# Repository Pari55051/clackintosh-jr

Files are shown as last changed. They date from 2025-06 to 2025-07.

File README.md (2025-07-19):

# Clackintosh Jr.
A macropad to accompany my mac and my keyboard 'Clackintosh'

## Features
- 8 mechanical keys
- Rotary encoder for volume up/down _ its switch as mute button
- 0.91" SSD1306 OLED display
- per-key RGB light
- Xiao RP2040 and KMK firmware

Each key launches a different app on macOS, the rotary encoder controls volume, and the OLED provides live feedback.

## Screenshots
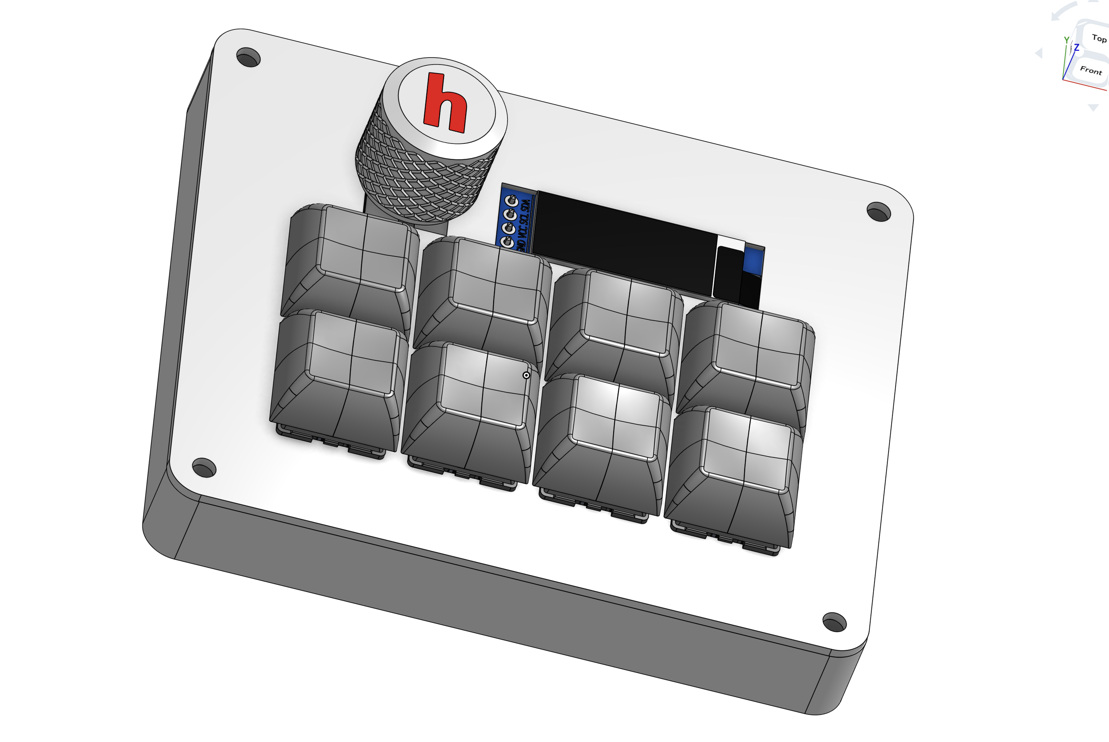
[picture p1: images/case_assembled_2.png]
case_assembled_2

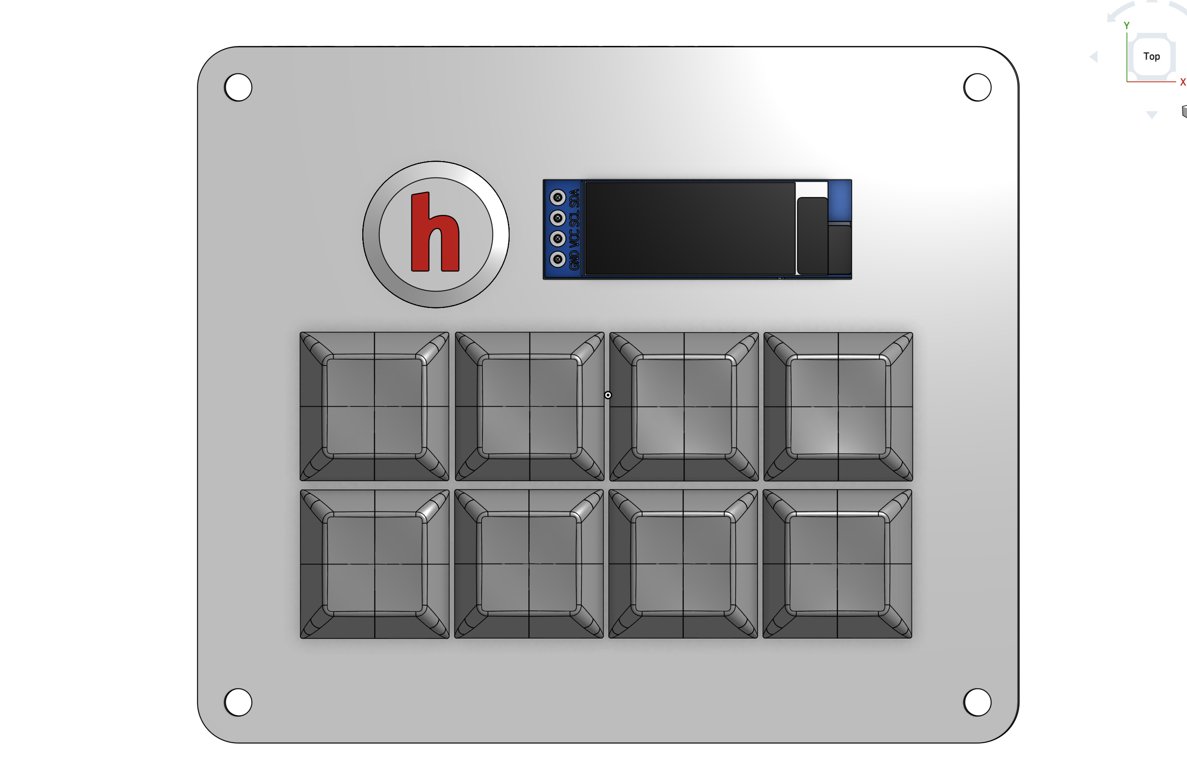
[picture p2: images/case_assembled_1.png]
case_assembled_1

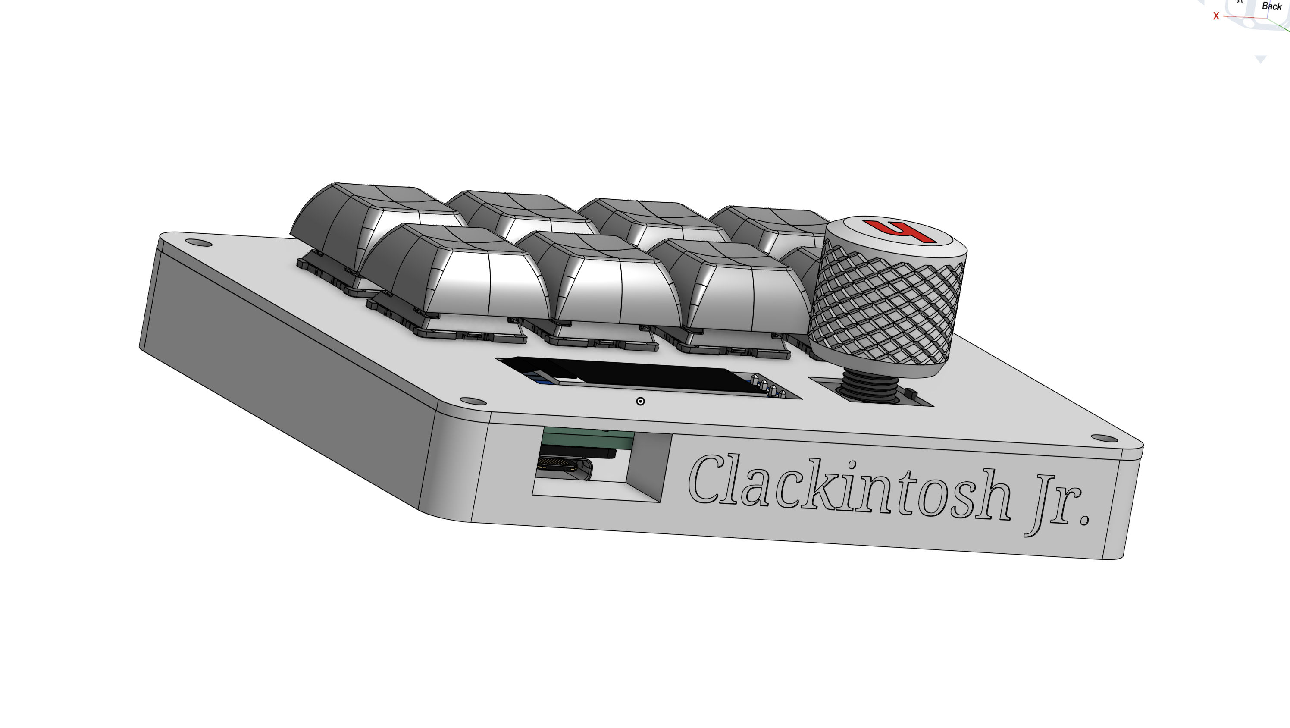
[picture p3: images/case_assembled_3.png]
case_assembled_3


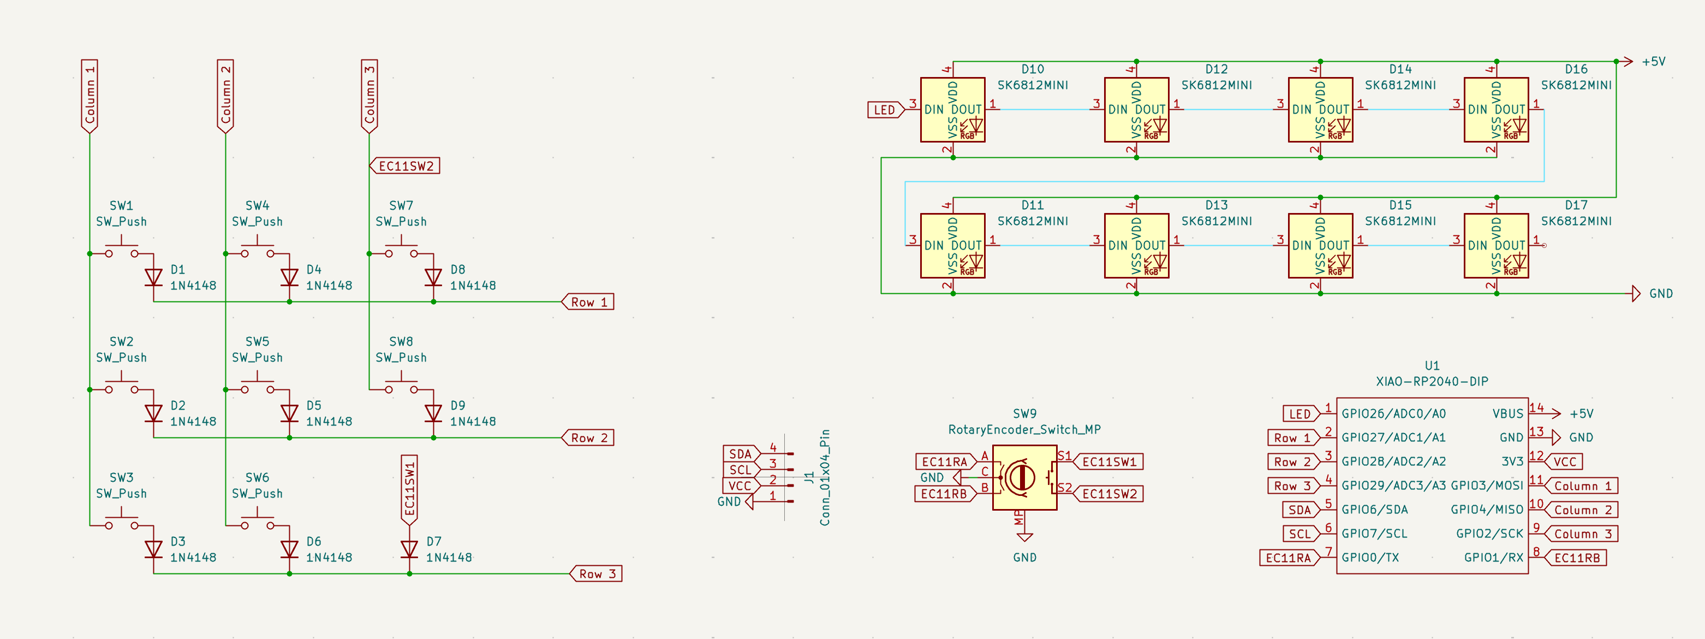
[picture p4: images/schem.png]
pcb_schematics

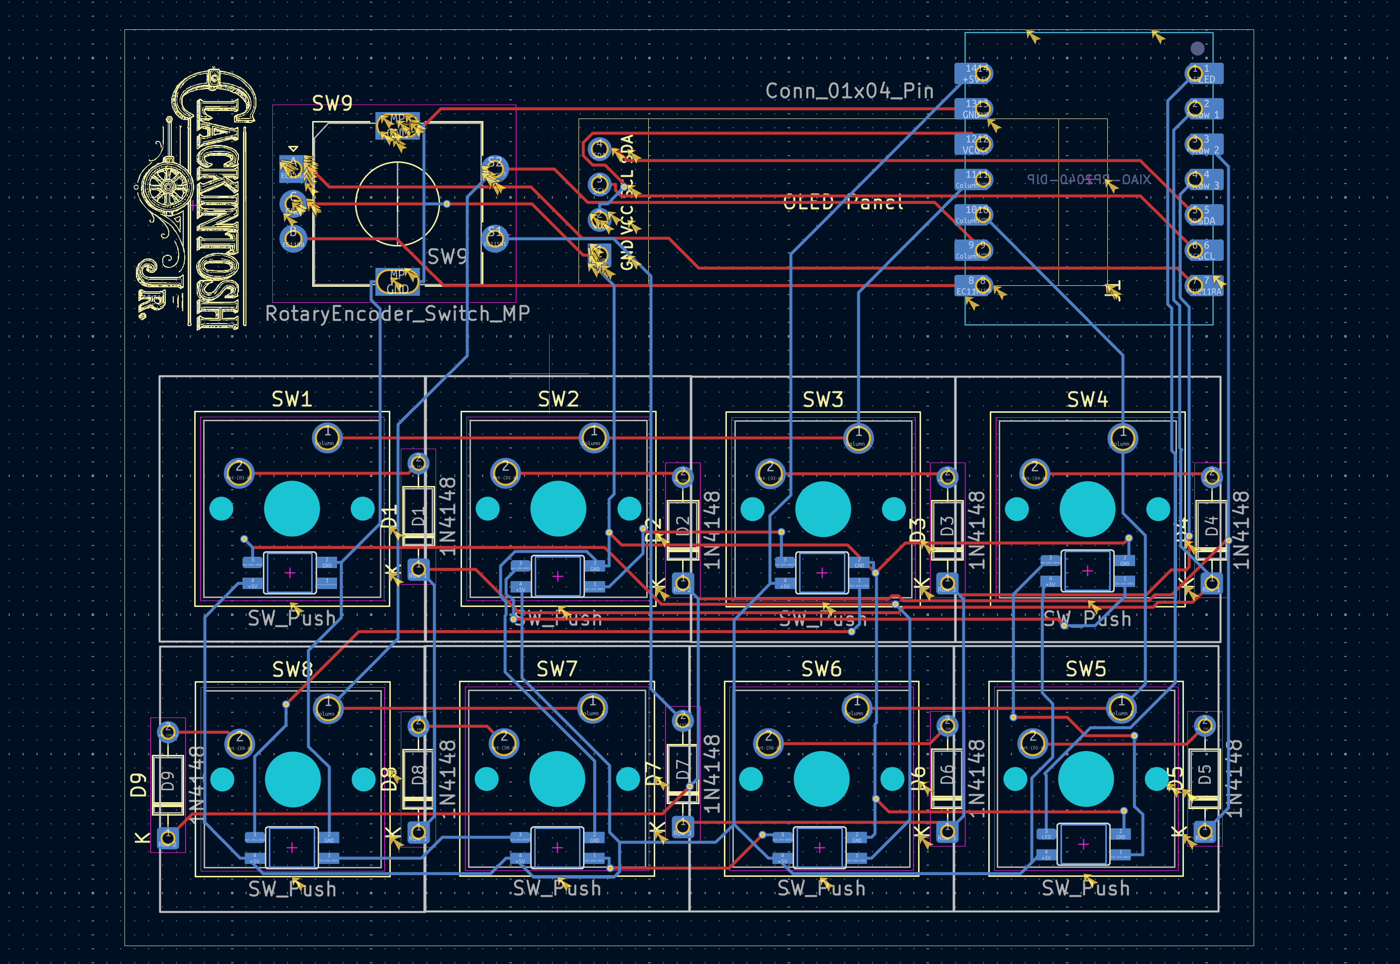
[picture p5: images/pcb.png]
pcb

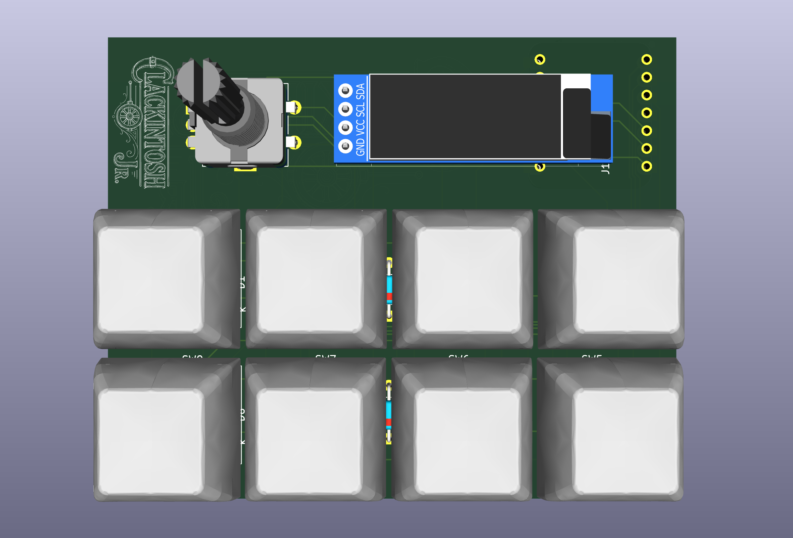
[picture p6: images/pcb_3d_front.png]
pcb_3d_front

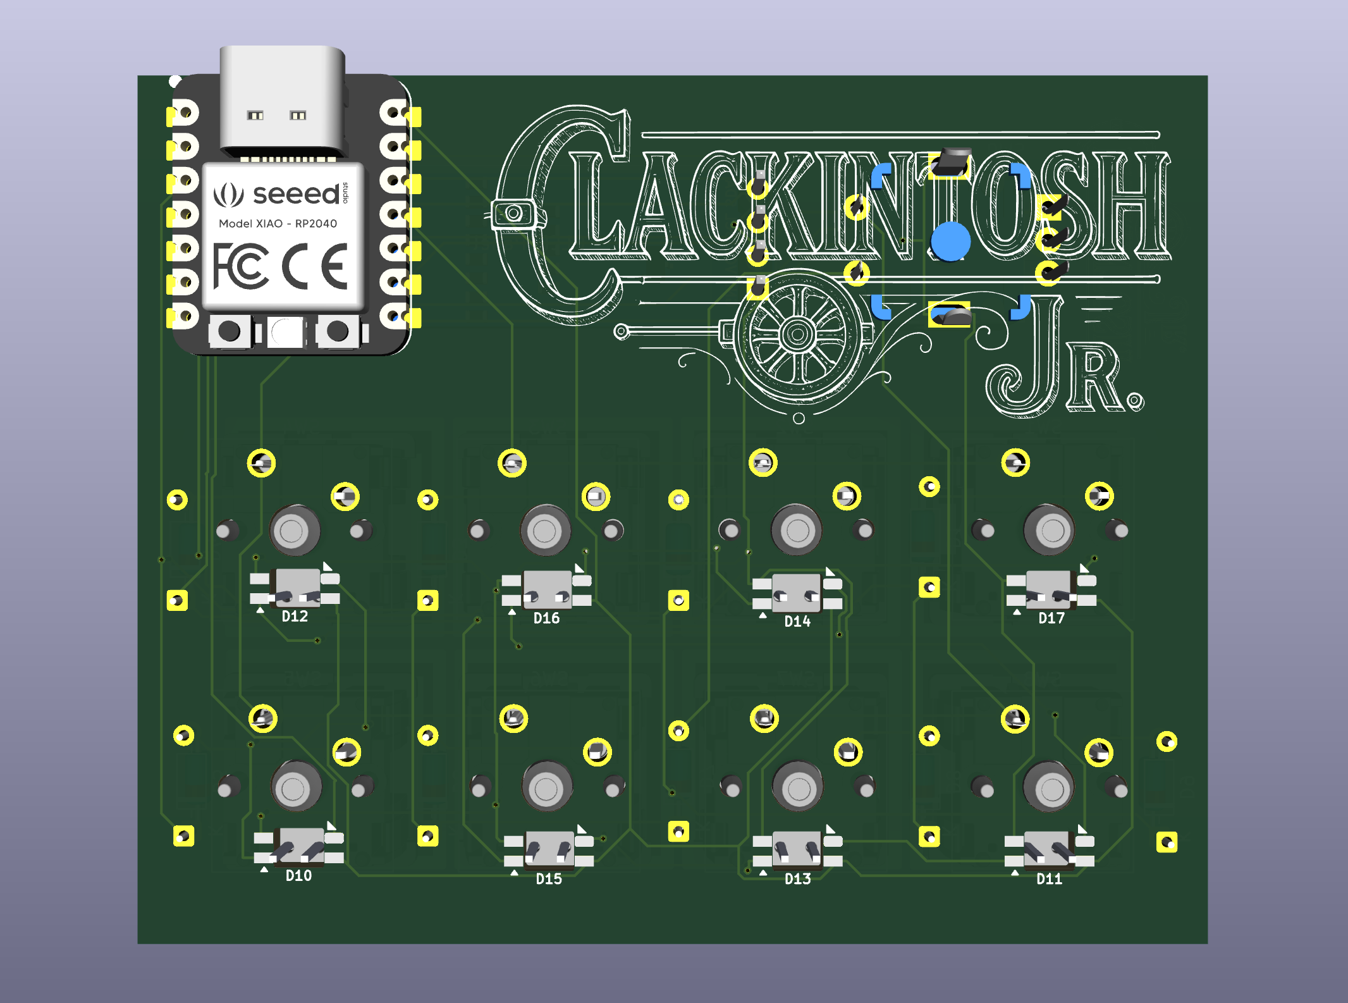
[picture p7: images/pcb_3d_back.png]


## BOM

| Item | Qty |
|---|-----|
| Seeed Xiao RP2040 | 1 |
| Mechanical switches | 8 |
| Keycaps | 8 |
| EC11Rotary Encoder | 1 |
| 0.91" OLED display | 1 |
| Diodes (for matrix) | 9 |
| PCB | 1 |
| 3D printed case (top + bottom) | 1 |
| Screws (case) | 4 |

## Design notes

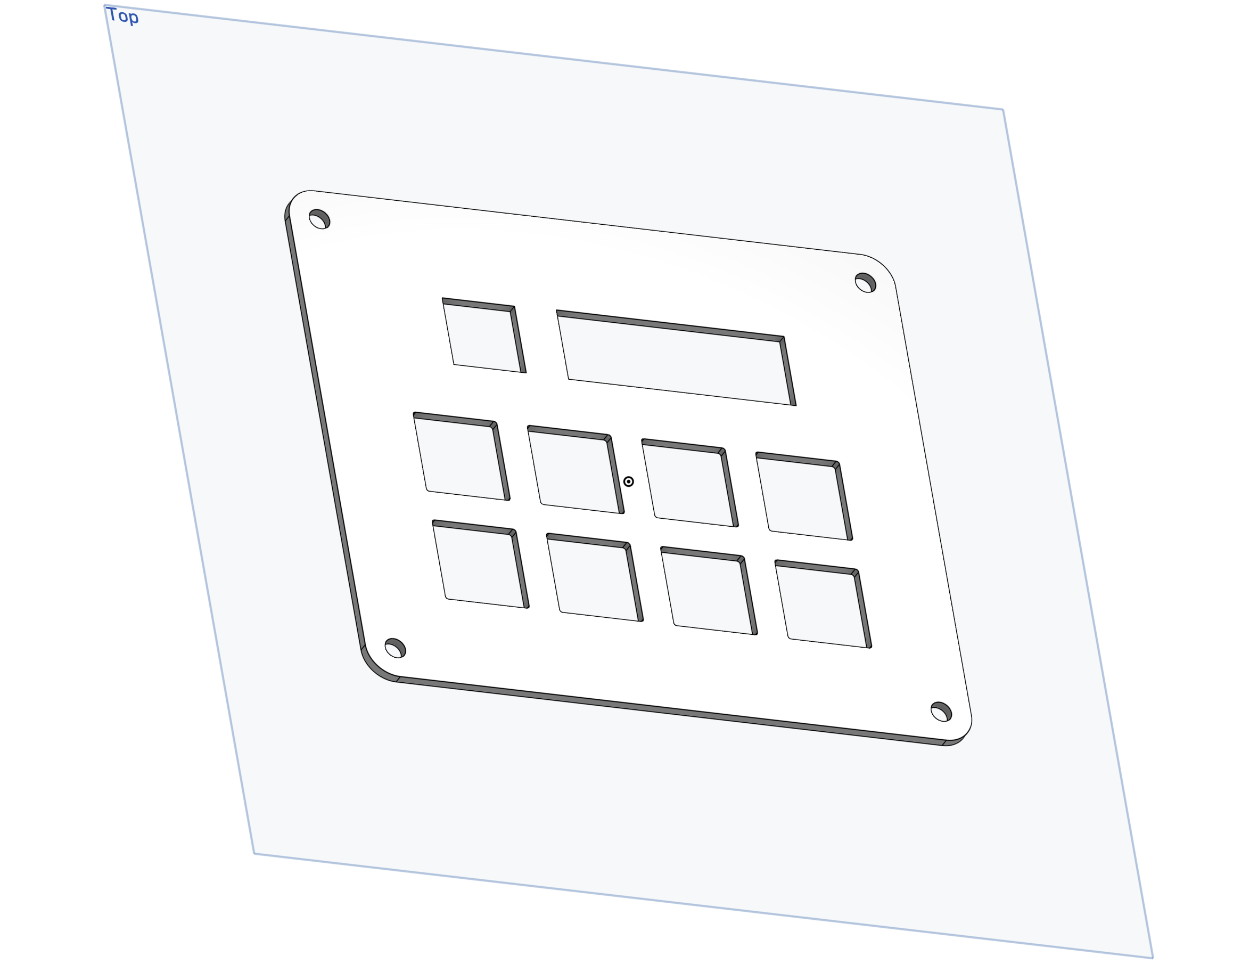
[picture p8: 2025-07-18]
images/case_top.png

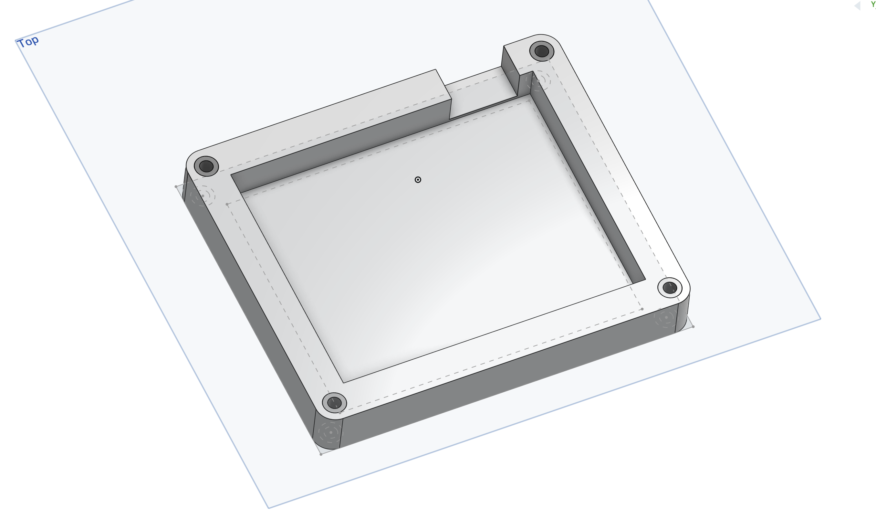
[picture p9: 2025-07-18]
images/case_bottom.png

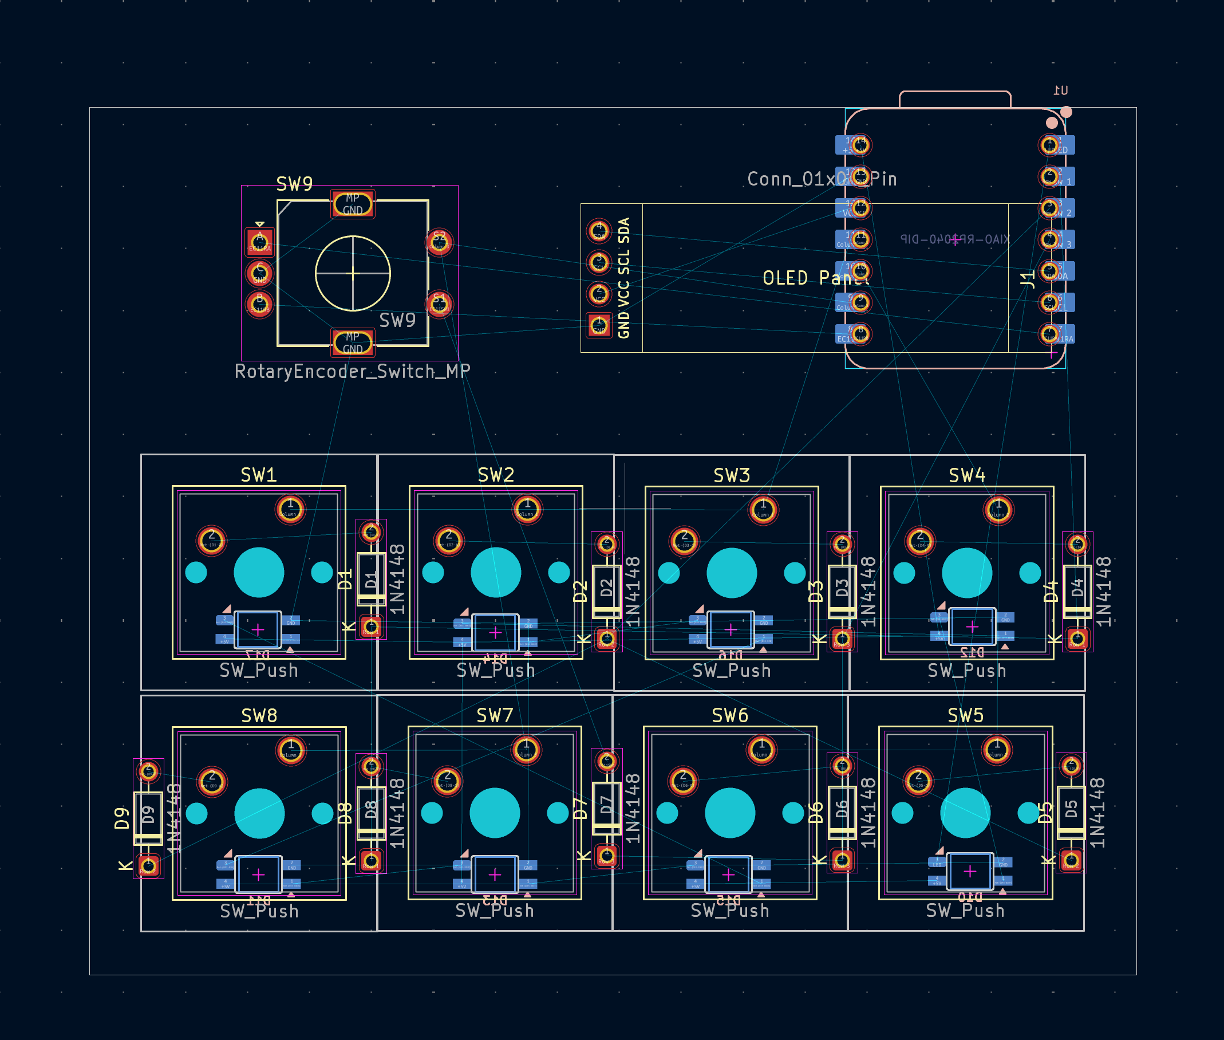
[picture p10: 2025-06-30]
images/pcb-unwired.png

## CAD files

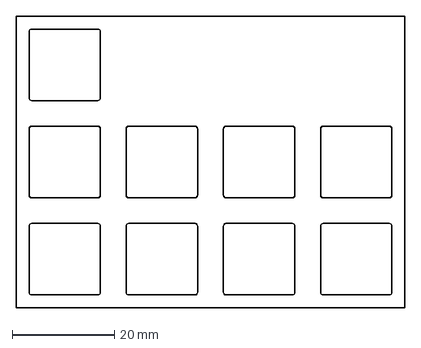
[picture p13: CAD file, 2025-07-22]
CAD/plate.dxf
76.2 x 57.1 mm

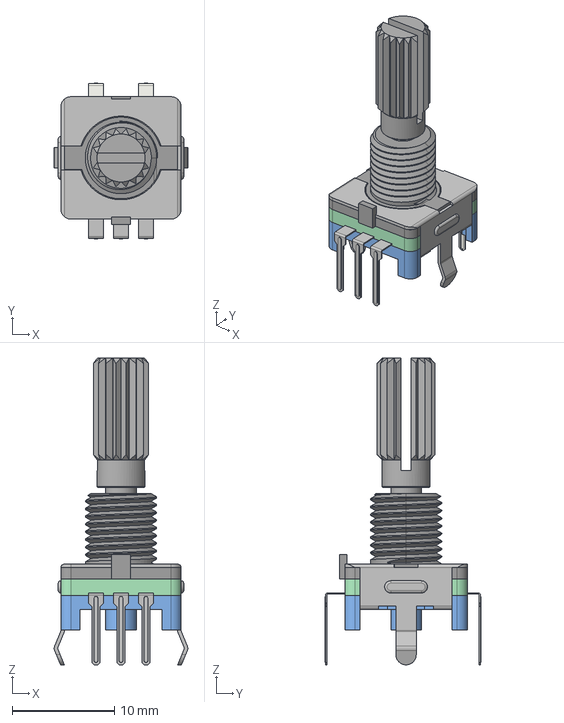
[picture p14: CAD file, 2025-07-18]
PCB/3d_files/EC11_Rotary_Encoder_Switched.step
13.1 x 15.3 x 30.1 mm

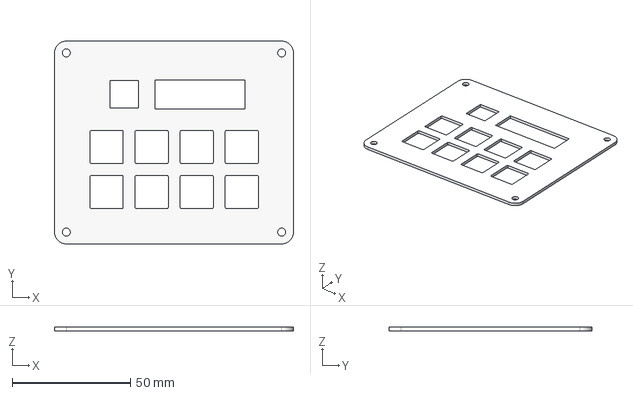
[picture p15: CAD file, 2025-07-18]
Production/Case Top.step
101.1 x 85.8 x 1.50 mm

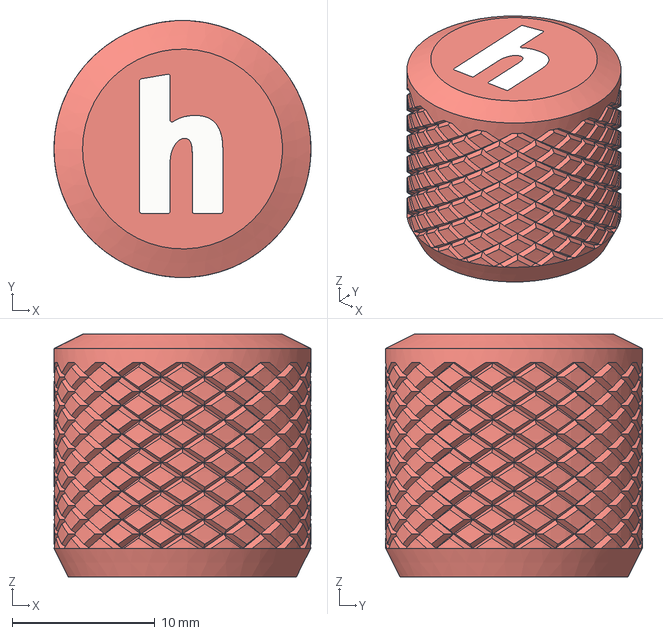
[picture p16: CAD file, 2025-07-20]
CAD/Knurled Knob.step
18.0 x 18.0 x 17.0 mm
Base
H

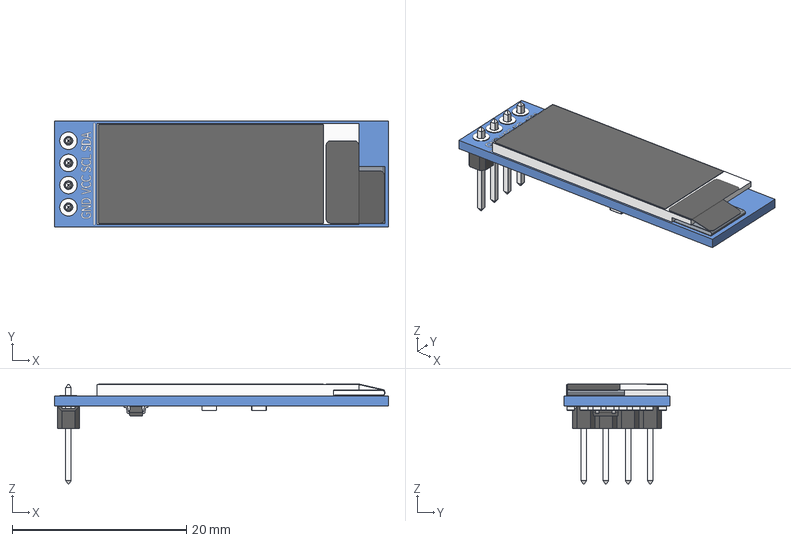
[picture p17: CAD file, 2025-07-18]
PCB/3d_files/NEW_OLED_0.91_128x32.stp
38.3 x 12.1 x 11.5 mm
OLED_0.91_128x32
Pin Header 4 x 1 TH 2.54mm Pitch
RESC-0603 x 13
2SD0601A

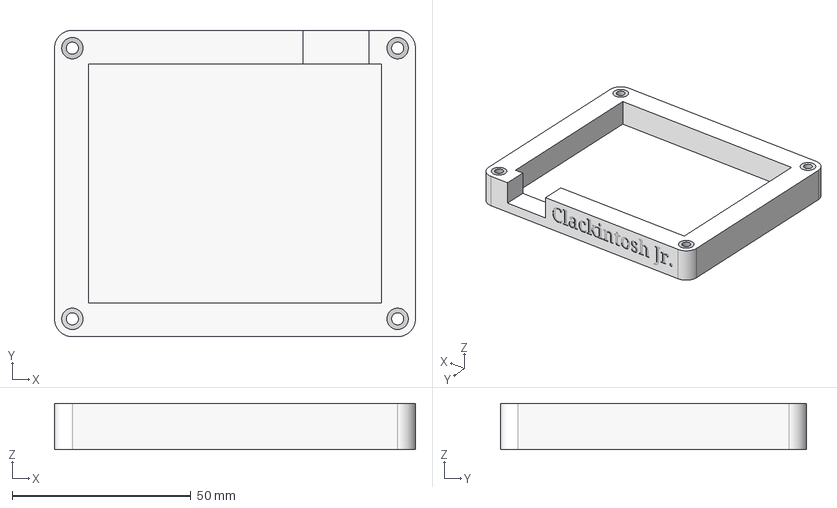
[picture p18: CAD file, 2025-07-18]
Production/Case Bottom.step
101.1 x 85.8 x 13.0 mm

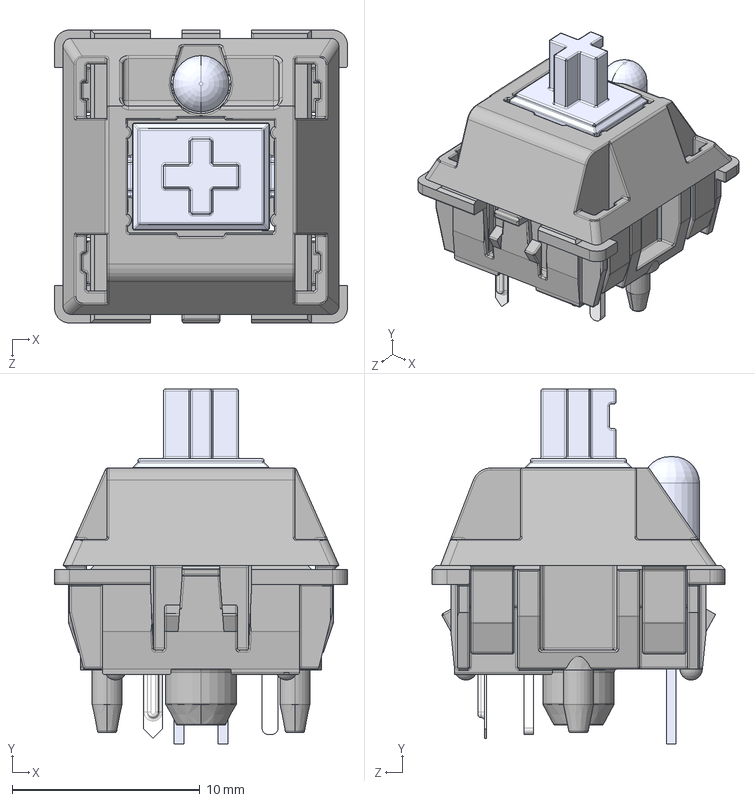
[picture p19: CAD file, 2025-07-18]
PCB/3d_files/cherry mx switch.step
15.6 x 18.9 x 15.6 mm
MX 轴 按键′_ü___¨1
MX 轴 轴体áì_¨￠¨__
MX粣 拸簽LEDLEDLED
MX轴 轴体 底部 μ×2__默认_á2____è_
针脚___默认__è_

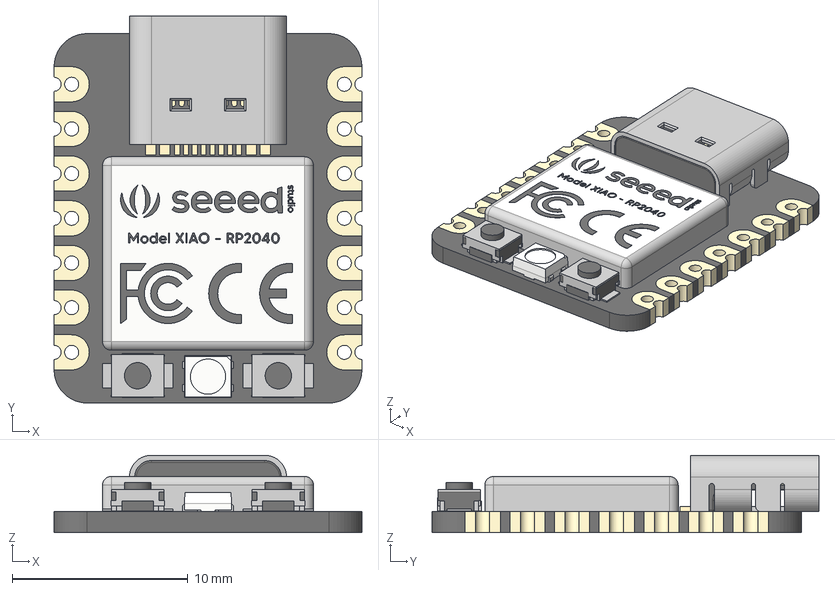
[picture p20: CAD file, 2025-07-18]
PCB/3d_files/Seeed Studio Xiao RP2040 v26.step
17.5 x 22.0 x 4.40 mm
type-c v2
smd_button v3
DOUT
DIN
VSS
VDD
smd_button v3(Mirror)

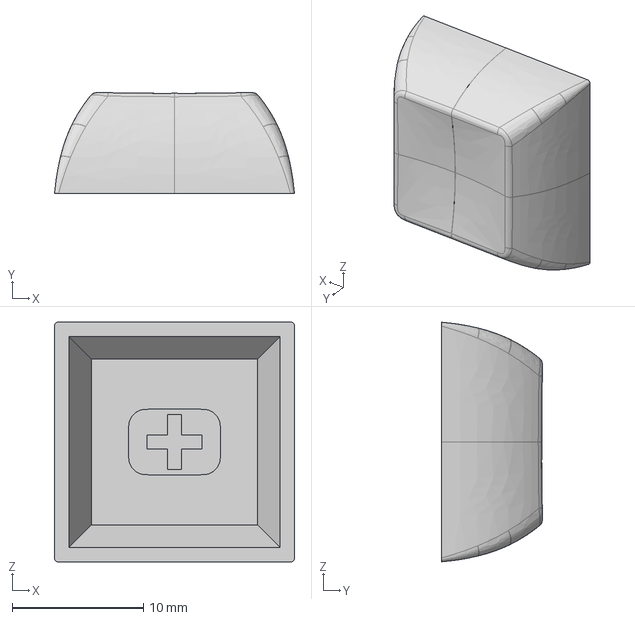
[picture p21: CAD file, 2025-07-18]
PCB/3d_files/keycap_cherrymx.step
18.3 x 7.69 x 18.3 mm

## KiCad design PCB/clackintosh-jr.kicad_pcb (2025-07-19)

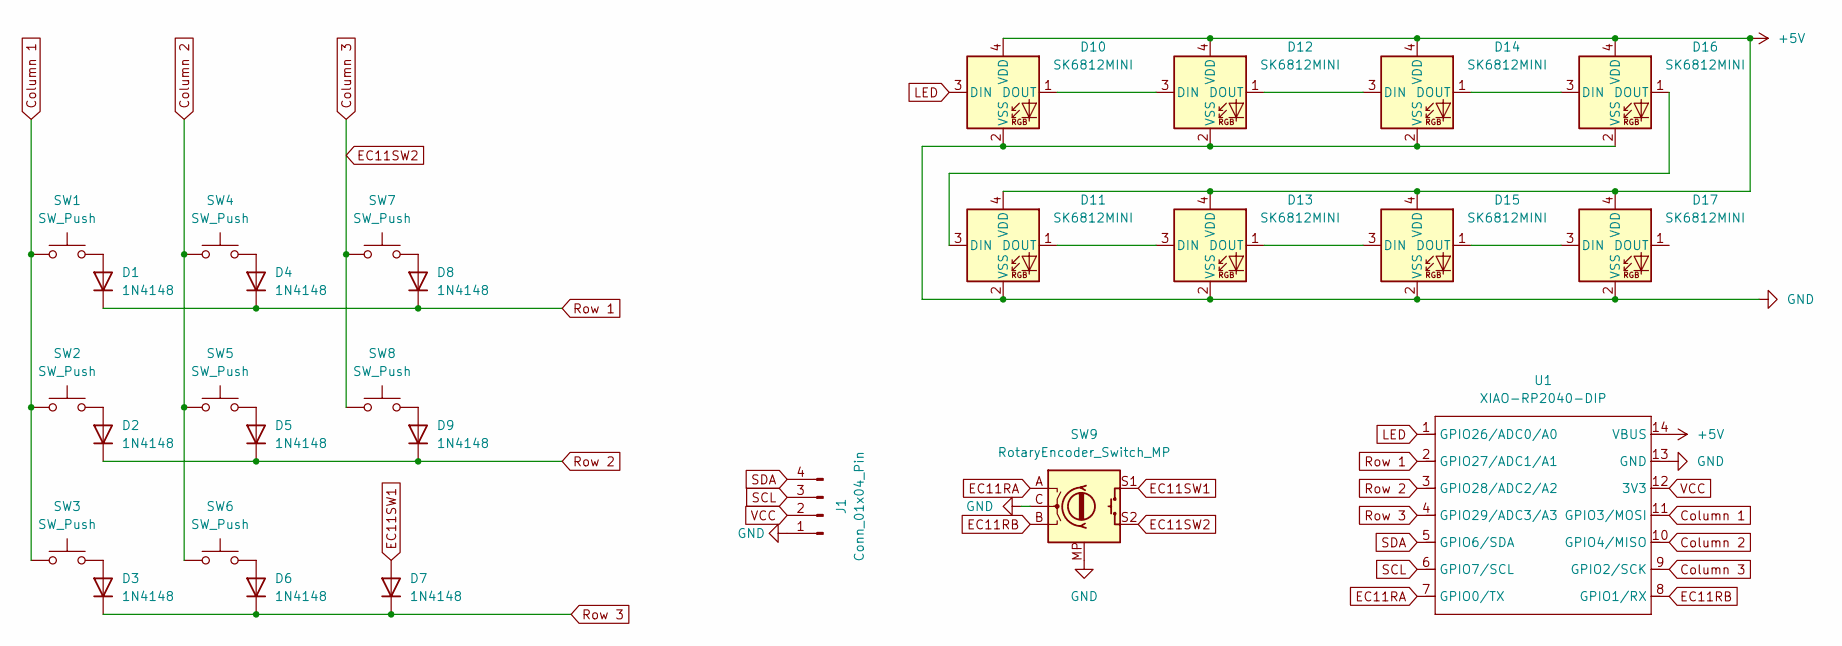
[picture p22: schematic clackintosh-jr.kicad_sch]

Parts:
D1, D2, D3, D4, D5, D6, D7, D8, D9: 1N4148; D_DO-35_SOD27_P7.62mm_Horizontal
D10, D11, D12, D13, D14, D15, D16, D17: SK6812MINI; SK6812-MINI-E
J1: Conn_01x04_Pin; SSD1306-0.91-OLED-4pin-128x32
SW1, SW2, SW3, SW4, SW5, SW6, SW7, SW8: SW_Push; SW_Cherry_MX_1.00u_PCB
SW9: RotaryEncoder_Switch_MP; RotaryEncoder_Alps_EC11E-Switch_Vertical_H20mm
U1: XIAO-RP2040-DIP

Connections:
+5V: D10.4 (VDD), D11.4 (VDD), D12.4 (VDD), D13.4 (VDD), D14.4 (VDD), D15.4 (VDD), D16.4 (VDD), D17.4 (VDD), U1.14 (VBUS)
Column 1: SW1.1, SW2.1, SW3.1, U1.11 (GPIO3/MOSI)
Column 2: SW4.1, SW5.1, SW6.1, U1.10 (GPIO4/MISO)
Column 3: SW7.1, SW8.1, SW9.S2, U1.9 (GPIO2/SCK)
EC11RA: SW9.A, U1.7 (GPIO0/TX)
EC11RB: SW9.B, U1.8 (GPIO1/RX)
EC11SW1: D7.2 (A), SW9.S1
GND: D10.2 (VSS), D11.2 (VSS), D12.2 (VSS), D13.2 (VSS), D14.2 (VSS), D15.2 (VSS), D16.2 (VSS), D17.2 (VSS), J1.1, SW9.C, SW9.MP, U1.13 (GND)
LED: D10.3 (DIN), U1.1 (GPIO26/ADC0/A0)
unnamed: D1.2 (A), SW1.2
unnamed: D2.2 (A), SW2.2
unnamed: D3.2 (A), SW3.2
unnamed: D4.2 (A), SW4.2
unnamed: D5.2 (A), SW5.2
unnamed: D6.2 (A), SW6.2
unnamed: D8.2 (A), SW7.2
unnamed: D9.2 (A), SW8.2
unnamed: D10.1 (DOUT), D12.3 (DIN)
unnamed: D11.3 (DIN), D16.1 (DOUT)
unnamed: D11.1 (DOUT), D13.3 (DIN)
unnamed: D12.1 (DOUT), D14.3 (DIN)
unnamed: D13.1 (DOUT), D15.3 (DIN)
unnamed: D14.1 (DOUT), D16.3 (DIN)
unnamed: D15.1 (DOUT), D17.3 (DIN)
Row 1: D1.1 (K), D4.1 (K), D8.1 (K), U1.2 (GPIO27/ADC1/A1)
Row 2: D2.1 (K), D5.1 (K), D9.1 (K), U1.3 (GPIO28/ADC2/A2)
Row 3: D3.1 (K), D6.1 (K), D7.1 (K), U1.4 (GPIO29/ADC3/A3)
SCL: J1.3, U1.6 (GPIO7/SCL)
SDA: J1.4, U1.5 (GPIO6/SDA)
VCC: J1.2, U1.12 (3V3)

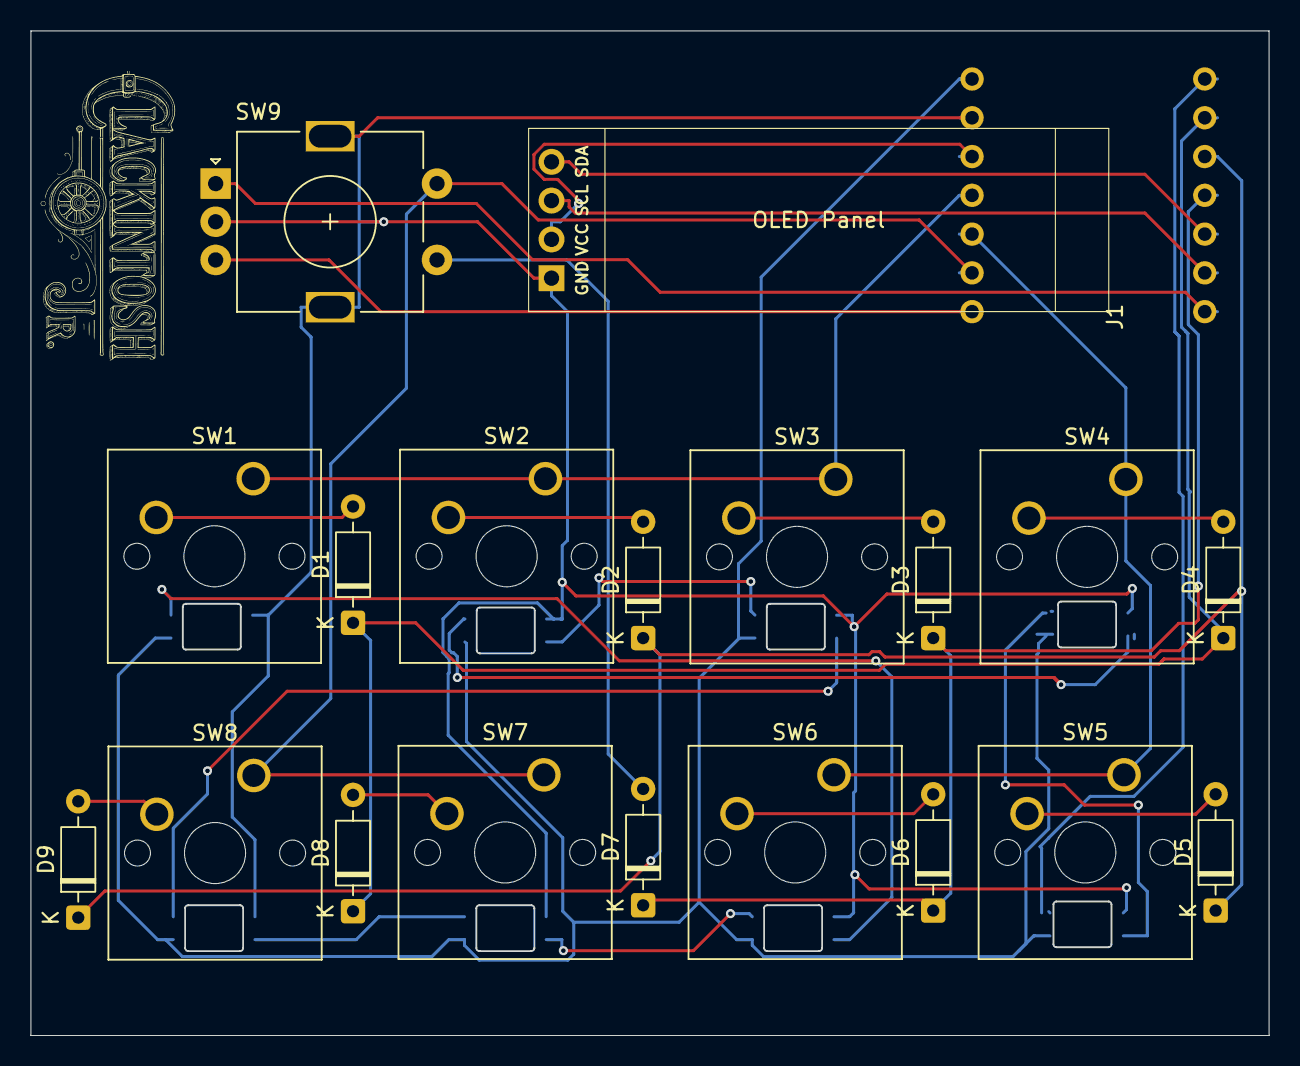
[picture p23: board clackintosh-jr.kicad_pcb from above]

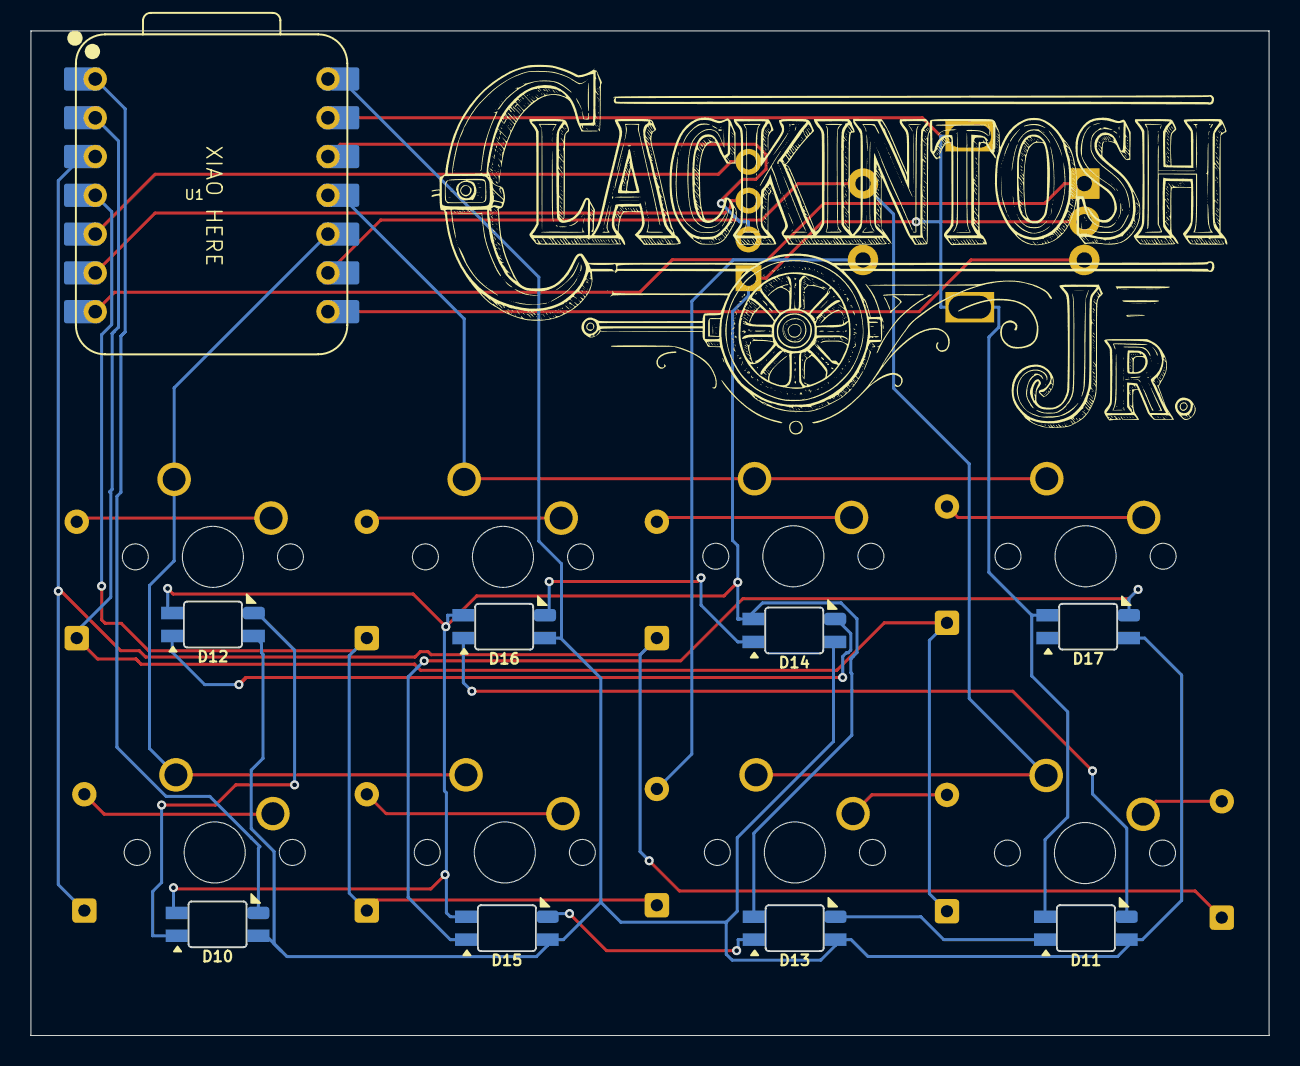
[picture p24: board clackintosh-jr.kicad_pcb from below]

Board: 2 copper layers, 81.1 x 65.8 mm, 28 parts (9 on the bottom side), 30 nets.

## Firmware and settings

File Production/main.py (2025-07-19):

# #import all IOs of board
# import board

# #imports from kmk libaray
# from kmk.kmk_keyboard import kmk_keyboard
# from kmk.scanners.keypad import KeysScanner
# from kmk.keys import KC
# from kmk.modules.macros import Press, Release, Tap, Macros

# #main instance of keyboard
# keyboard = KMKKeyboard()

# #adding macro extension
# macros = Macros()
# keyboard.modules.append(macros)

# # DEFINE PINS
# PINS = [board.A0, board.A1, board.A2, board.A3, board.D6, board.D7. board.D0, board.D3, board.D4, board.D2, board.D1]

# # not using matrix code
# keyboard.matrix = KeysScanner(
#     pins = PINS,
#     value_when_pressed = False,
# )

# # DEFINE BUTTONS corresp to pins
# keyboard.keymap = [
#     KC.A, KC.DELETE, KC.MACRO("Hello World"), KC.Macro(Press(KC.LCMD), Tap(KC.S), Release(KC.LMD)),
# ]

# # start kmk
# if __name__ == '__main__':
#     keyboard.go()

# print("Starting")

################################################################
import board
import displayio
import terminalio
from time import sleep

from kmk.kmk_keyboard import KMKKeyboard
from kmk.keys import KC
from kmk.scanners import DiodeOrientation

from kmk.modules.encoder import EncoderHandler
import adafruit_displayio_ssd1306
from adafruit_display_text import label

# for opening apps - via macros - through spotlight
def spotlight_open(app_name):
    def macro_function(keyboard):
        # Open Spotlight
        keyboard.tap_code(KC.LGUI)
        keyboard.tap_code(KC.SPACE)
        sleep(0.1)
        # Type app name
        for letter in app_name:
            key = getattr(KC, letter.upper(), None)
            if key:
                keyboard.tap_code(key)
                sleep(0.01)
        # Press Enter
        keyboard.tap_code(KC.ENTER)
    return macro_function

# matrix setup
keyboard = KMKKeyboard()
keyboard.col_pins = (board.GP3, board.GP4, board.GP2)    
keyboard.row_pins = (board.GP27, board.GP28, board.GP29)  
keyboard.diode_orientation = DiodeOrientation.COL2ROW

# oled setup
displayio.release_displays()
i2c = board.I2C()
display_bus = displayio.I2CDisplay(i2c, device_address=0x3C)
WIDTH = 128
HEIGHT = 32
display = adafruit_displayio_ssd1306.SSD1306(display_bus, width=WIDTH, height=HEIGHT)
splash = displayio.Group()
display.show(splash)
status_text = label.Label(terminalio.FONT, text="Clackintosh Jr.", color=0xFFFFFF, x=5, y=18)
splash.append(status_text)

# RE setup
encoder = EncoderHandler()
keyboard.modules.append(encoder)
encoder.pins = ((board.GP0, board.GP1),)
encoder.map = [((KC.VOLU, KC.VOLD),)]

# keymap - all trigger func via macro only
keyboard.keymap = [
    [KC.NO, KC.NO, KC.NO], 
    [KC.NO, KC.NO, KC.NO],
    [KC.NO, KC.NO, KC.NO],
]

# key-app mapping
app_macros = [
    ("Arc", "Arc open!"),                     # Row 1 Col 1
    ("Mail", "Mail open!"),                   # Row 1 Col 2
    ("Terminal", "Terminal open!"),           # Row 1 Col 3
    ("Notes", "Notes open!"),                 # Row 2 Col 1
    ("Spotify", "Spotify open!"),             # Row 2 Col 2
    ("Fantastical", "Fantastical open!"),     # Row 2 Col 3
    ("Todoist", "Todoist open!"),             # Row 3 Col 1
    ("Whatsapp", "Whatsapp open!"),           # Row 3 Col 2
    (None, "Muted!"),                         # Row 3 Col 3 (rotary encoder switch)
]

# key press macro
def custom_key_handler(event):

    if event.pressed:
        key_index = event.key_number

        if key_index < len(app_macros):

            app_name, display_msg = app_macros[key_index]
            status_text.text = display_msg

            if app_name is None:
                keyboard.tap_code(KC.MUTE)
            else:
                spotlight_open(app_name)(keyboard)
                
    else:
        status_text.text = "Clackintosh Jr."

keyboard.key_down_handler = custom_key_handler

if __name__ == '__main__':
    keyboard.go()

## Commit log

2025-07-18 case done + minor updates to pcb
    [Case Bottom.step, Case Top.step, EC11_Rotary_Encoder_Switched.step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]
2025-07-19 update readme + production folder
    [Case Bottom.step, Case Top.step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]
